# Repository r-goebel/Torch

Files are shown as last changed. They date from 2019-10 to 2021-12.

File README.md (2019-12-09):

# LED torch
On the EH18 I got the idea to put an LED strip on a cardboard tube to use the full 5m without having to unwind and wind it all the time. The connections for 5V will be installed permanently and can easily be plugged in later. For the effects an ESP is installed, which is also powered via the 5V connection. 

## Material
  * cardboard shipping roll (D=80mm; L=600mm(?))
  * 5m LED Strip (WS2812b; Amazon)
  * Wemos D1 mini (ESP8266)
  * 3 Capacitor (1000 µF)
  * Resistor 470 Ohm
  * Resistor 10k Ohm 
  * Diode
  * Cable (For power and data)
  * Power supply 5V (up to now max. 2A --> Maximum brightness not higher than 20)
  * XT30 for connection between power supply and torch
  * MR30 for connection between Power suppli/PCB and the LEDstrip
  
  For an advanced look:
  * Laser-cutted wood box (housing for PCB and Torch-Mount)
  * Lamp Foil and Sandwich paper for light scattering

## Effects
This project additionally needs the Effect-library: https://github.com/r-goebel/Effects

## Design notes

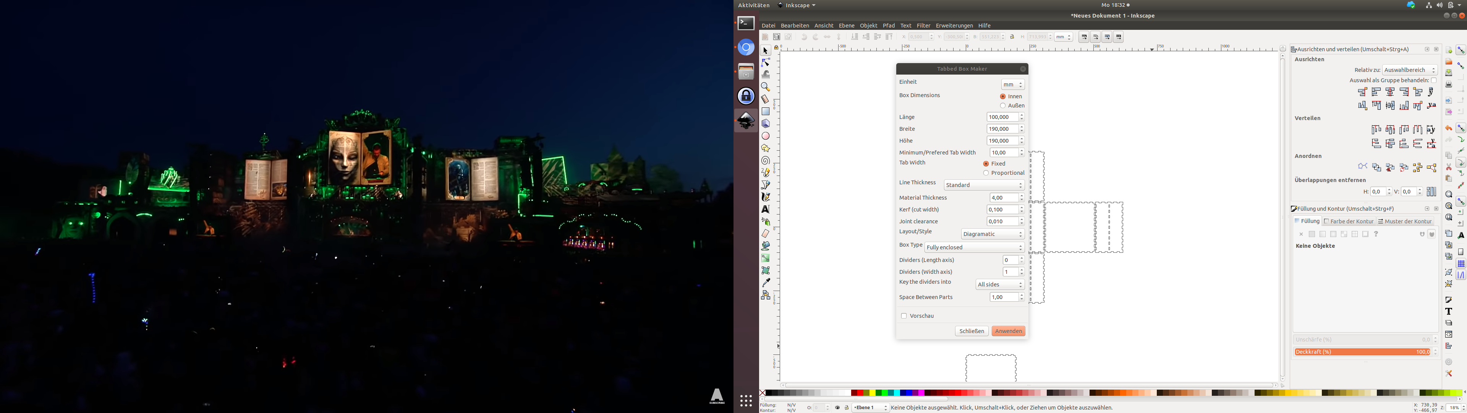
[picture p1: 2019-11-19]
Laser/Settings Boxgenerator unten.png

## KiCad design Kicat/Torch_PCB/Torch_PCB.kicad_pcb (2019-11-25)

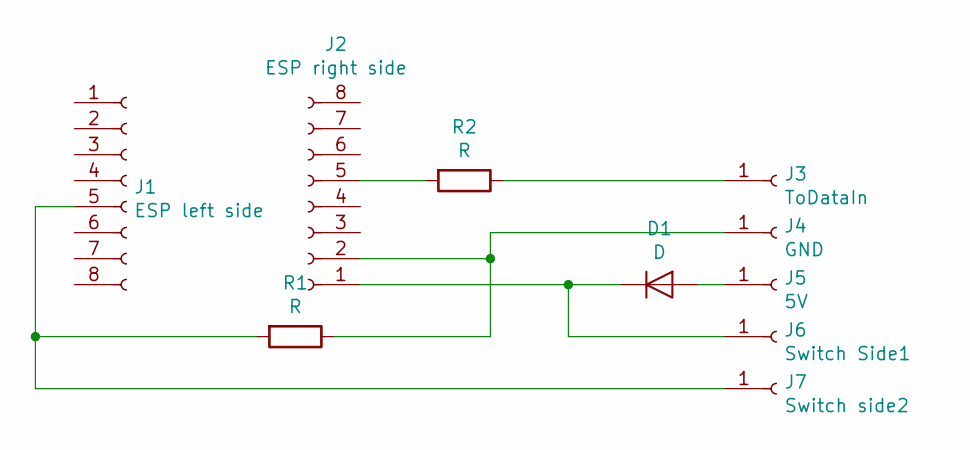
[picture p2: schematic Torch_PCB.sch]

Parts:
D1: D; D_5W_P10.16mm_Horizontal
J1: ESP left side; PinSocket_1x08_P2.54mm_Vertical
J2: ESP right side; PinSocket_1x08_P2.54mm_Vertical
J3: ToDataIn; PinSocket_1x01_P2.54mm_Vertical
J4: GND; PinSocket_1x01_P2.54mm_Vertical
J5: 5V; PinSocket_1x01_P2.54mm_Vertical
J6: Switch Side1; PinSocket_1x01_P2.54mm_Vertical
J7: Switch side2; PinSocket_1x01_P2.54mm_Vertical
R1, R2: R; R_Axial_DIN0207_L6.3mm_D2.5mm_P10.16mm_Horizontal

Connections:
unnamed: D1.1 (K), J2.1, J6.1
unnamed: D1.2 (A), J5.1
unnamed: J1.5, J7.1, R1.2
unnamed: J2.2, J4.1, R1.1
unnamed: J2.5, R2.2
unnamed: J3.1, R2.1

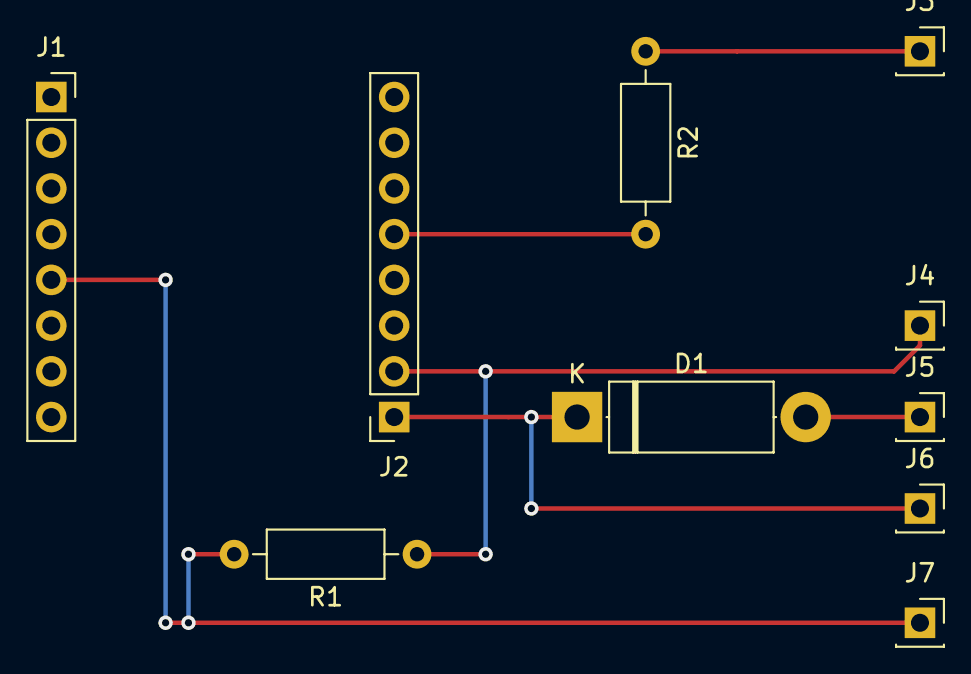
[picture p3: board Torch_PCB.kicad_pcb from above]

Board: 2 copper layers, 10 parts (0 on the bottom side), 6 nets.

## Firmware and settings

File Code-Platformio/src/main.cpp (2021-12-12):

#include <Arduino.h>

//Include necessary libraries
//#include <ESP8266WiFi.h>
#include <Homie.h>
#include <Effects.h>
#include <ArduinoOTA.h>

//Definition of Neopixelstrip-Variables:
#define PixelPin D2
int NumPixel = 300;
int NumRows = 19;
int NumCols = 16;
Effects strip = Effects(NumPixel, PixelPin, NEO_GRB + NEO_KHZ800);

//Definition of HomieNode
HomieNode EffectNode("EffectNode", "EffectNode", "Effect");
HomieNode ColorNode("ColorNode", "ColorNode", "Color");
HomieNode PowerNode("PowerNode","powerNode","Power");
HomieNode RestartNode("RestartNode", "RestartNode","Restart");

//Definition of possible effects and colors
char* effectList[] = {"fade","cylon","twinkle", "twinkle random", "sparkle", "sparkle random", "color wipe", "rainbow cycle", "theater", "theater rainbow", "fire", "ice fire", "meteor rain", "rain", "marble", "heart beat"};
int ColorSelection[] = {1,1,1,0,1,0,1,0,1,0,0,0,1,1,0,1}; //1 if color selection for corresponding Effect possible
int NumberEffects = 16;
char* colorList[] ={"red","yellow","green","cyan","blue","magenta","white"};
int colorListRGB[7] = {strip.Color(255,0,0),  //red
                       strip.Color(255,255,0),//yellow
                       strip.Color(0,255,0),  //green
                       strip.Color(0,255,255),//cyan
                       strip.Color(0,0,255),  //blue
                       strip.Color(255,0,255),//magenta
                       strip.Color(255,255,255)};//white
                       
int NumberColors = 7; 

//Definition of various variables
int colorDefault = 1;         //default color if nothing is selected by client
int Selected[] = {1,0};       //initial definition of selected effect and color
int SelectedNew[] = {random(0,NumberEffects),random(0,NumberColors)};    //initial definition of new selected effect and color   
bool EffectChange = 1;        //variable indication change in effect (0=no change, 1=change), initially one change necessary  
int EffectLengthMax = 20;     //Length of longes effect-name in effectList

bool powerOn = true;
bool restartOn = true;

//Definition of Switch
#define PinSwitch D6
int intervalSwitch = 500; //interval in which no new Switch is allowed
int lastSwitch;

//++++++++++++++++++++++++++++++++++++
//Homie-Loop Functions
//++++++++++++++++++++++++++++++++++++
bool effectHandler(const HomieRange& range, const String& effect){
  //effect in Liste raussuchen
  for (int i=0; i<NumberEffects; i++) {
    if (effect == effectList[i]) {
      SelectedNew[0] = i;
      break;
    }
    else {
      SelectedNew[0] = 0;
    }
  }
  EffectChange = 1;
  EffectNode.setProperty("effect").send(effect);

  return true;
}

bool colorHandler(const HomieRange& range, const String& color){
  //color in Liste raussuchen
  for (int i=0; i<NumberColors; i++) {
    if (color == colorList[i]) {
      SelectedNew[1] = i;
      break;
    }
    else {
      SelectedNew[1] = 0;
    }
  }
  EffectChange = 1;
  ColorNode.setProperty("color").send(color);

  return true;
}


bool powerHandler(const HomieRange& range, const String& value){
  if (value == "false"){
    powerOn = false;
    strip.clear();
    strip.show();
  } else {
    powerOn = true;
    EffectChange = 1;
  }
  Serial.println("PowerOn: " + String(powerOn));
  PowerNode.setProperty("poweron").send(value);

  return true;
}

//++++++++++++++++++++++++++++++++++++
//OTA Functions
//++++++++++++++++++++++++++++++++++++
void OTASetup(){
  //Setup off OTA, must be called during setup
  //Equals Basic OTA example
  ArduinoOTA.onStart([]() {
  String type;
  if (ArduinoOTA.getCommand() == U_FLASH) {
    type = "sketch";
  } else { // U_FS
    type = "filesystem";
  }

  // NOTE: if updating FS this would be the place to unmount FS using FS.end()
  Serial.println("Start updating " + type);
  });
  ArduinoOTA.onEnd([]() {
    Serial.println("\nEnd");
  });
  ArduinoOTA.onProgress([](unsigned int progress, unsigned int total) {
    Serial.printf("Progress: %u%%\r", (progress / (total / 100)));
  });
  ArduinoOTA.onError([](ota_error_t error) {
    Serial.printf("Error[%u]: ", error);
    if (error == OTA_AUTH_ERROR) {
      Serial.println("Auth Failed");
    } else if (error == OTA_BEGIN_ERROR) {
      Serial.println("Begin Failed");
    } else if (error == OTA_CONNECT_ERROR) {
      Serial.println("Connect Failed");
    } else if (error == OTA_RECEIVE_ERROR) {
      Serial.println("Receive Failed");
    } else if (error == OTA_END_ERROR) {
      Serial.println("End Failed");
    }
  });
}

//++++++++++++++++++++++++++++++++++++
//Helperfunctions
//++++++++++++++++++++++++++++++++++++
void SelectEffect (){
  if (Selected[0] == 0){
    strip.FadeInOut(colorListRGB[Selected[1]],10); 
    
  } else if (Selected[0] == 1){
    strip.Cylon(colorListRGB[Selected[1]], 4, 10);
    
  } else if (Selected[0] == 2){ //Twinkle
    strip.Twinkle(colorListRGB[Selected[1]],10,250);
       
  }else if (Selected[0] == 3){ //TwinkleRandom
    strip.Twinkle(colorListRGB[Selected[1]],10,250,1);
    
  }else if (Selected[0] == 4){ //Sparkle
    strip.Sparkle(colorListRGB[Selected[1]],0);
    
  }else if (Selected[0] == 5){ //SparkleRandom
    strip.Sparkle(colorListRGB[Selected[1]],0,1);
    
  }else if (Selected[0] == 6){ //ColorWipe
    strip.colorWipe(colorListRGB[Selected[1]],50);
    
  } else if (Selected[0] == 7){ //RainbowCycle
    strip.rainbowCycle(10);
    
  } else if (Selected[0] == 8){ //TheaterChase
    strip.theaterChase(colorListRGB[Selected[1]]);
    
  } else if (Selected[0] == 9){ //TheaterChaseRainbow
    strip.theaterChase(colorListRGB[Selected[1]],1);
    
  } else if (Selected[0] == 10){ //Fire
    strip.fireSpiral(NumCols);
    
  } else if (Selected[0] == 11){ //Ice Fire
    strip.fireSpiral(NumCols,1,100,175);
      
  } else if (Selected[0] == 12){ //Meteor Rain
    strip.meteorRainSpiral(colorListRGB[Selected[1]],NumCols);
  
  } else if (Selected[0] == 13){ //Rain without wind
    strip.rainSpiral(colorListRGB[Selected[1]],0,NumCols);
  
  }else if (Selected[0] == 14){ //Marble
    strip.rollingMarble(10);
  
  }else if (Selected[0] == 15){ //Heart Beat
    strip.heartBeat(colorListRGB[Selected[1]]);
  
  }
}

bool SwitchState;

bool CheckSwitch(){
  //Check switch state
  SwitchState = digitalRead(PinSwitch);
    
  //if Sensor value exceeds limit
  if(SwitchState == HIGH){
    //Change Effect randonly
    SelectedNew[0] = random(NumberEffects-1);
    SelectedNew[1] = random(NumberColors-1);
    EffectChange = 1;
    EffectNode.setProperty("effect").send(effectList[SelectedNew[0]]);
    ColorNode.setProperty("color").send(colorList[SelectedNew[1]]);
  }
    
  else{
    EffectChange = 0;
  }

  return EffectChange;
}

//++++++++++++++++++++++++++++++++++++
//Main Functions
//++++++++++++++++++++++++++++++++++++

void setup() {
  //Homie
  Homie_setFirmware("Torch", "1.0.0"); // The underscore is not a typo! See Magic bytes
  //Homie.setLoopFunction(loopHandler);
  //Node.advertise("PropertyID").setName("PropertyName").setDatatype("datatype").setUnit("unit");
  EffectNode.advertise("effect").setName("Effect").setDatatype("String").settable(effectHandler);
  ColorNode.advertise("color").setName("Color").setDatatype("String").settable(colorHandler);
  PowerNode.advertise("poweron").setName("PowerOn").setDatatype("String").settable(powerHandler);
  RestartNode.advertise("restart").setName("Restart").setDatatype("String");

  Homie.setup();

  OTASetup();
  ArduinoOTA.begin();
  
  Serial.begin(115200);

  delay(1000);

  //initialization of strip
  strip.begin();
  strip.setBrightness(20); //maximum 20 is possible, 25 should work as well, not sure
  strip.show();
}

void loop() {
  //Read input via Homie/Dashboard
  Homie.loop();
  ArduinoOTA.handle();
  
  //get last state after restart
  if (restartOn == true && Homie.isConfigured() && Homie.isConnected()){
    RestartNode.setProperty("restart").send("true"); // send restart notice to node red
    restartOn = false;
    Serial.println("restart initialized");
  }
  

  //if no input was recived from homie, check switch
  if (EffectChange == 0 && millis()-lastSwitch > intervalSwitch){
    EffectChange = CheckSwitch();

       if (EffectChange == 1){
        lastSwitch = millis();
        powerOn = true;
       }
  }

  if (powerOn == true){
    //new effect selected: replace effect and color in "Selected", initialize new effect if needed, reset "EffectChange"
    if (EffectChange == 1){
      Serial.println("EffectChange noticed");
      Selected[0] = SelectedNew[0];
      Selected[1] = SelectedNew[1];
      EffectChange = 0;
      strip.clear();
      //Initialization
      SelectEffect();
    }
    //client did not select anything new or no client is availabel: just update effect
    else{
      strip.Update();
    }
  }
}

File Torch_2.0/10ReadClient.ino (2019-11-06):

//Definition of Messages sent to client
char* Messages[] = {"Welcome",
                    "To list available effects, type 'help'.",
                    "Please select effect: ",
                    "Succesfully selected effect.",
                    "Input did not match any effect.",
                    "Do you wish to select color (y/n)?",
                    "Selected random color: ",
                    "Please select color: ",
                    "Succesfully selected color.",
                    "Input did not match any color.",
                    "Effect is changed now.",
                    "Available effects:",
                    "Available colors:",
                    "To list available colors, type 'help'",
                    "Selected random effect: "};

int clientStatus;
int i;
                        
bool ReadClient(bool EffectChange){
  if (!client.connected()){ 
  //no client is connected: try to connect new one, ClientStatus = 0, return to loop
    clientStatus = 0;
    client = server.available();
  }
  else { //client is connected
    
    //New client connected: Welcome-Message-Package, set ClientStatus to 1
    if (clientStatus == 0){
      client.println(Messages[0]);
      client.println(Messages[1]);
      clientStatus = 1;    
    }

    //ClientStatus 1: Ask for effect selection, set ClientStatus to 2
    if (clientStatus == 1){
      client.print(Messages[2]);
      clientStatus = 2;
    }

    //ClientStatus > 2: Read client input
    if (client.available() > 0 && clientStatus > 1) { 
      i = 0;  
      char incomingMessage[EffectLengthMax];  
      while (client.available() > 0 && i < EffectLengthMax) {
        delay(10);     
        incomingMessage[i] = client.read();

        if (incomingMessage[i] == '\n' || incomingMessage[i] == '\r'){
          incomingMessage[i] = '\0';                    //delets last character
          i = EffectLengthMax;
        } 
        i++;
      }

      //Evaluate Message:
       
      //ClientStatus 2: evaluate input of effect
      if (clientStatus == 2){
        //Input equals "help": sent Message 11, print list of effects, set clientStatus to 1
        if (strcmp(incomingMessage, "help") == 0){
          client.println(Messages[11]);
          for (int k=0;k<NumberEffects;k++){
            client.println(effectList[k]);
          }
          client.println("random");
          clientStatus = 1;
        }
        //Input is something else, check list of effects for Match
        else{
          int Match = 0;
          for (int k=0;k<NumberEffects;k++){
          //Input equals effect name: Change value of SelectedNew[0]
            if (strcmp(incomingMessage,effectList[k]) == 0){
              SelectedNew[0] = k;
              Match = 1;
              client.println(Messages[3]);
            }
          }
          //Same for random effect but sent Message 14
          if (strcmp(incomingMessage, "random") == 0){
            SelectedNew[0] = random(NumberEffects-1);
            Match = 1;
            client.print(Messages[14]);
            client.println(effectList[SelectedNew[0]]);
          }
            //selected effect needs color selection: sent Message 5, set clientStatus to 3
            if (ColorSelection[SelectedNew[0]] == 1 && Match == 1){
               client.print(Messages[5]);
              clientStatus = 3;
            }
            
            //selected effect does not need color selection: sent Message 10, set clientStatus to 1
            else if (ColorSelection[SelectedNew[0]] == 0 && Match == 1){
              client.println(Messages[10]);
              clientStatus = 1;
              EffectChange = 1;
            }

          //Input does not match any effect: sent Message 4&1, set clientSatus to 1
          if (Match == 0){
            client.println(Messages[4]);
            client.println(Messages[1]);
            clientStatus = 1;
          }
        }           
      }//End of if clientStatus = 2
        
      //ClientStatus 3: evaluate input for color-selection (y/n)
      else if (clientStatus == 3){
        
        //Input equals "n": Change value in SelectNew[1] to radom color, sent Message 6&10, chnage EffectChange to 1, set clientStatus to 1
        if (strcmp(incomingMessage, "n") == 0){
          SelectedNew[1] = random(NumberColors-1);
          client.print(Messages[6]);
          client.println(colorList[SelectedNew[1]]);
          client.println(Messages[10]);
          EffectChange = 1;
          clientStatus = 1;
        }
        
        //Input equals "y": sent Message 13&7, set clientStatus to 4
        else if (strcmp(incomingMessage, "y") == 0){
          client.println(Messages[13]);
          client.print(Messages[7]);
          clientStatus = 4;
        }

        //Input does not match y or n: sent specific Message and Message 5 
        else {
          client.println("Unknown input.");
          client.println(Messages[5]);            
        }
      }//End of if clientStatus = 3
        
      //ClientStatus 4: evaluate input of color
      else if (clientStatus = 4){
        
        //Input equals "help": sent Message 12&7, print list of colors
        if (strcmp(incomingMessage, "help") == 0){
          client.println(Messages[12]);
          for (int k=0;k<NumberColors;k++){
            client.println(colorList[k]);
          }
          client.println("random");
          client.print(Messages[7]);
        }

        //Input is something else, check list of colors for Match
        else{
          int Match = 0;
          for (int k=0;k<NumberColors;k++){
          //Input equals color name: Change value of SelectedNew[1], sent Message 8&10, chnage EffectChange to 1,set clientStatus to 1
            if (strcmp(incomingMessage,colorList[k]) == 0){
              SelectedNew[1] = k;
              Match = 1;
              client.println(Messages[8]);
              client.println(Messages[10]);
              EffectChange = 1;
              clientStatus = 1;
            }
          }
          //Same for random color but send Message 6&10
          if (strcmp(incomingMessage, "random") == 0){
            SelectedNew[1] = random(NumberColors-1);
            Match = 1;
            client.print(Messages[6]);
            client.println(colorList[SelectedNew[1]]);
            client.println(Messages[10]);
            EffectChange = 1;
            clientStatus = 1;
          }
          //Input does not match any color: sent Message 9&13&7
          if (Match == 0){
            client.println(Messages[9]);
            client.println(Messages[13]);
            client.print(Messages[7]);
          }
        }          
      }//End of if clientStatus = 4
    }//End of if client.available and clientStatus > 1
  }//end of else (client connected)
  
  //return EffectChange (only set to 1 if effect/color was changed, otherwise equals input value)
  return EffectChange;
}

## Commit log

2019-09-28 Basisprogramm welches erstmal mit einem Programm und ohne Wlan läuft
2019-09-28 Ende des Tages
2019-10-28 diverses und Basic code für ein effect
    [Fakel.kicad_pcb, Fakel.sch]
2019-11-02 Renamed Kicat-files
    [Torch.kicad_pcb, Torch.sch]
2019-11-02 Renamed files
    [Fakel.kicad_pcb, Fakel.sch]
2019-11-02 „README.md“ hinzufügen
2019-11-06 missed to put change indicator
    [10ReadClient.ino, 20SelectEffect.ino]
2019-11-07 removed camel case in effect list
2019-11-09 changed code for twinkle, problem with crashes of esp
    [20SelectEffect.ino]
2019-11-10 „README.md“ ändern
2019-11-19 Laser datei eingefügt
2019-11-25 Kicat files updated
    [Torch_PCB.kicad_pcb, Torch_PCB.sch]
2019-11-25 files laser final
2019-12-03 updatet sketches for laser
2019-12-03 added Touch sensor
2019-12-03 removed Serial print
2019-12-03 Added touch to Kicat files
    [Torch.sch, Torch_PCB.kicad_pcb, Torch_PCB.sch]
2019-12-09 reset touch intervall and higher brightness
    [Torch_2.0.ino]
2019-12-09 replaced Touch by common switch due to Malefunctions
    [Torch_2.0.ino]
2019-12-09 deleted touch from Kicat files
    [Torch.sch, Torch_PCB.kicad_pcb, Torch_PCB.sch]
2021-12-12 added Node res flow
